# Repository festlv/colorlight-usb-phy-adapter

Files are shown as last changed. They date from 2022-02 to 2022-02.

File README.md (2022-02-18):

USB ULPI phy for Colorlight i5 SOM development board
------------------------------------------------------

Hardware design for dual-PMOD style USB ULPI phy breakout board. 

By default, the design assumes that 24MHz oscillator provides clock to phy, and 60MHz clock generated by PHY is routed to FPGA.
It is possible to supply 24MHz clock from FPGA- see schematic for details.

The design is most likely compatible with several SMSC/Microchip USB phy's from the same series, using different oscillator frequencies (for instance, this board
was first designed for USB3317C, but it went out of stock while the board was designed).

Change history
--------------------

__Revision 0__:

   * VDD1.8 was not connected, as I assumed USB3315C has internal 1.8V regulator. It does not.
   * After bodging a regulator, the design enumerates using LUNA gateware

__Revision 1__:

   * Added 1.8V LDO which was required for the used phy

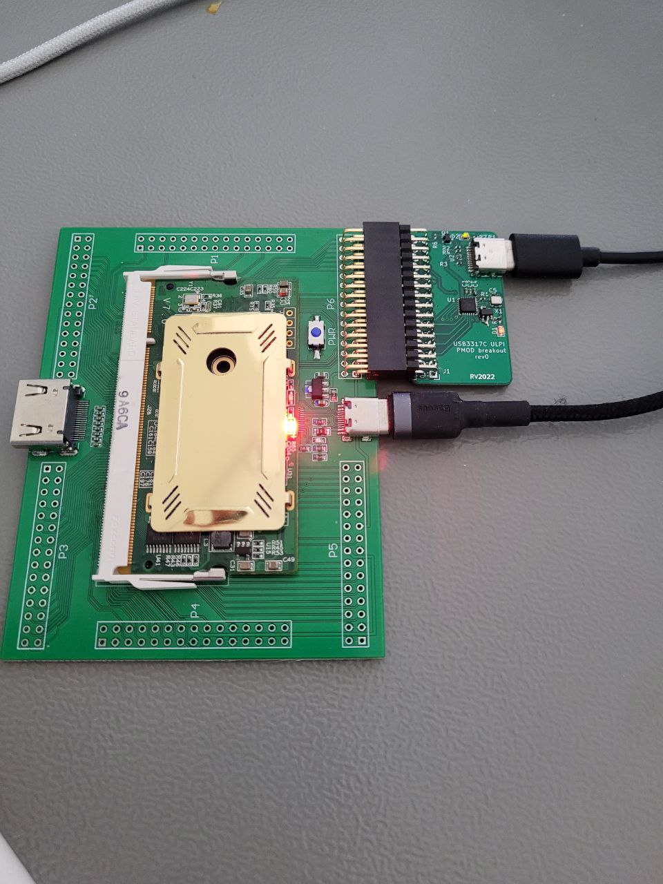
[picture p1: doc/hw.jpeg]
Image of hardware connected to colorlight i5 development board


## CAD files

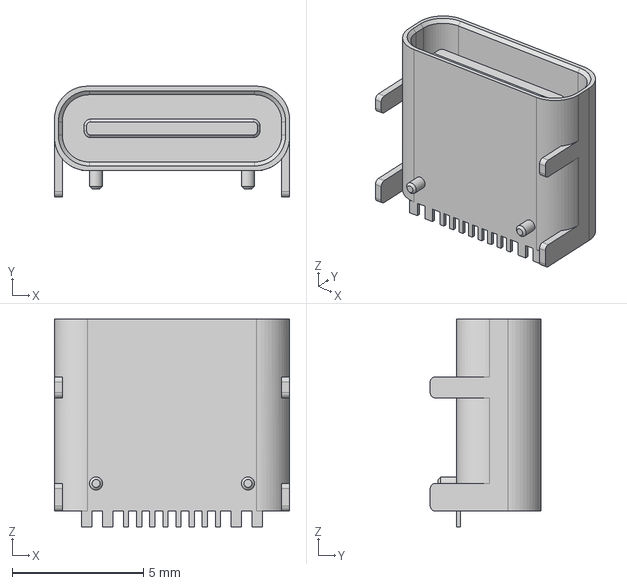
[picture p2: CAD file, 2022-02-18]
HRO TYPE-C-31-M-12.step
8.94 x 4.21 x 7.90 mm

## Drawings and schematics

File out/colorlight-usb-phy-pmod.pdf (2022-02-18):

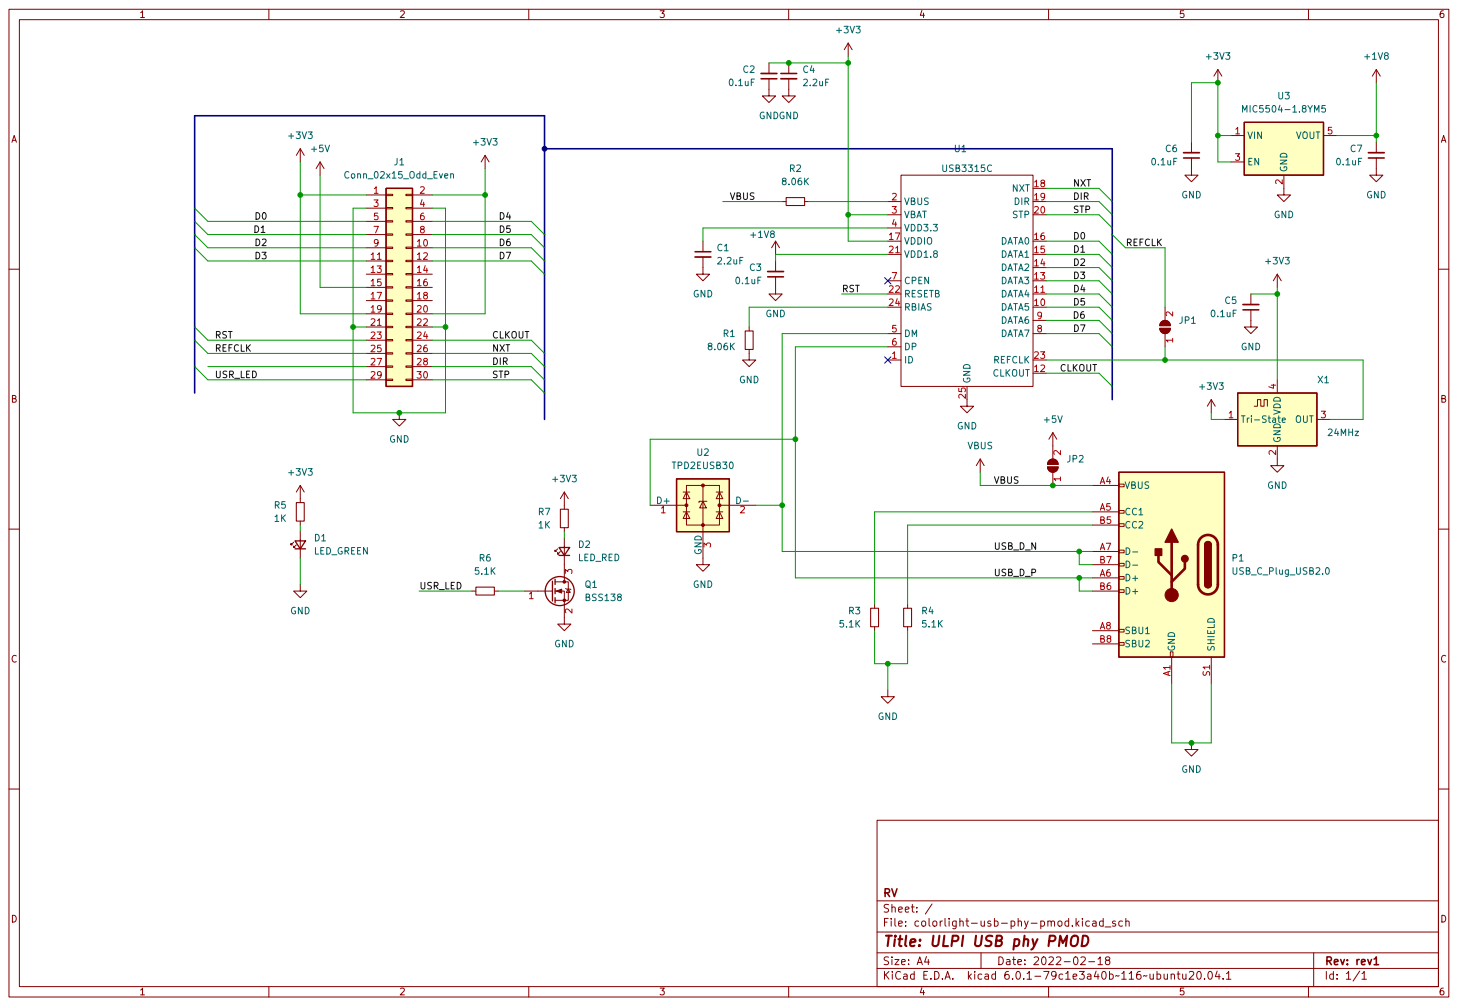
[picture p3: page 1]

File: colorlight-usb-phy-pmod.kicad_sch Sheet: / RV

Id: 1/1 Title: ULPI USB phy PMOD

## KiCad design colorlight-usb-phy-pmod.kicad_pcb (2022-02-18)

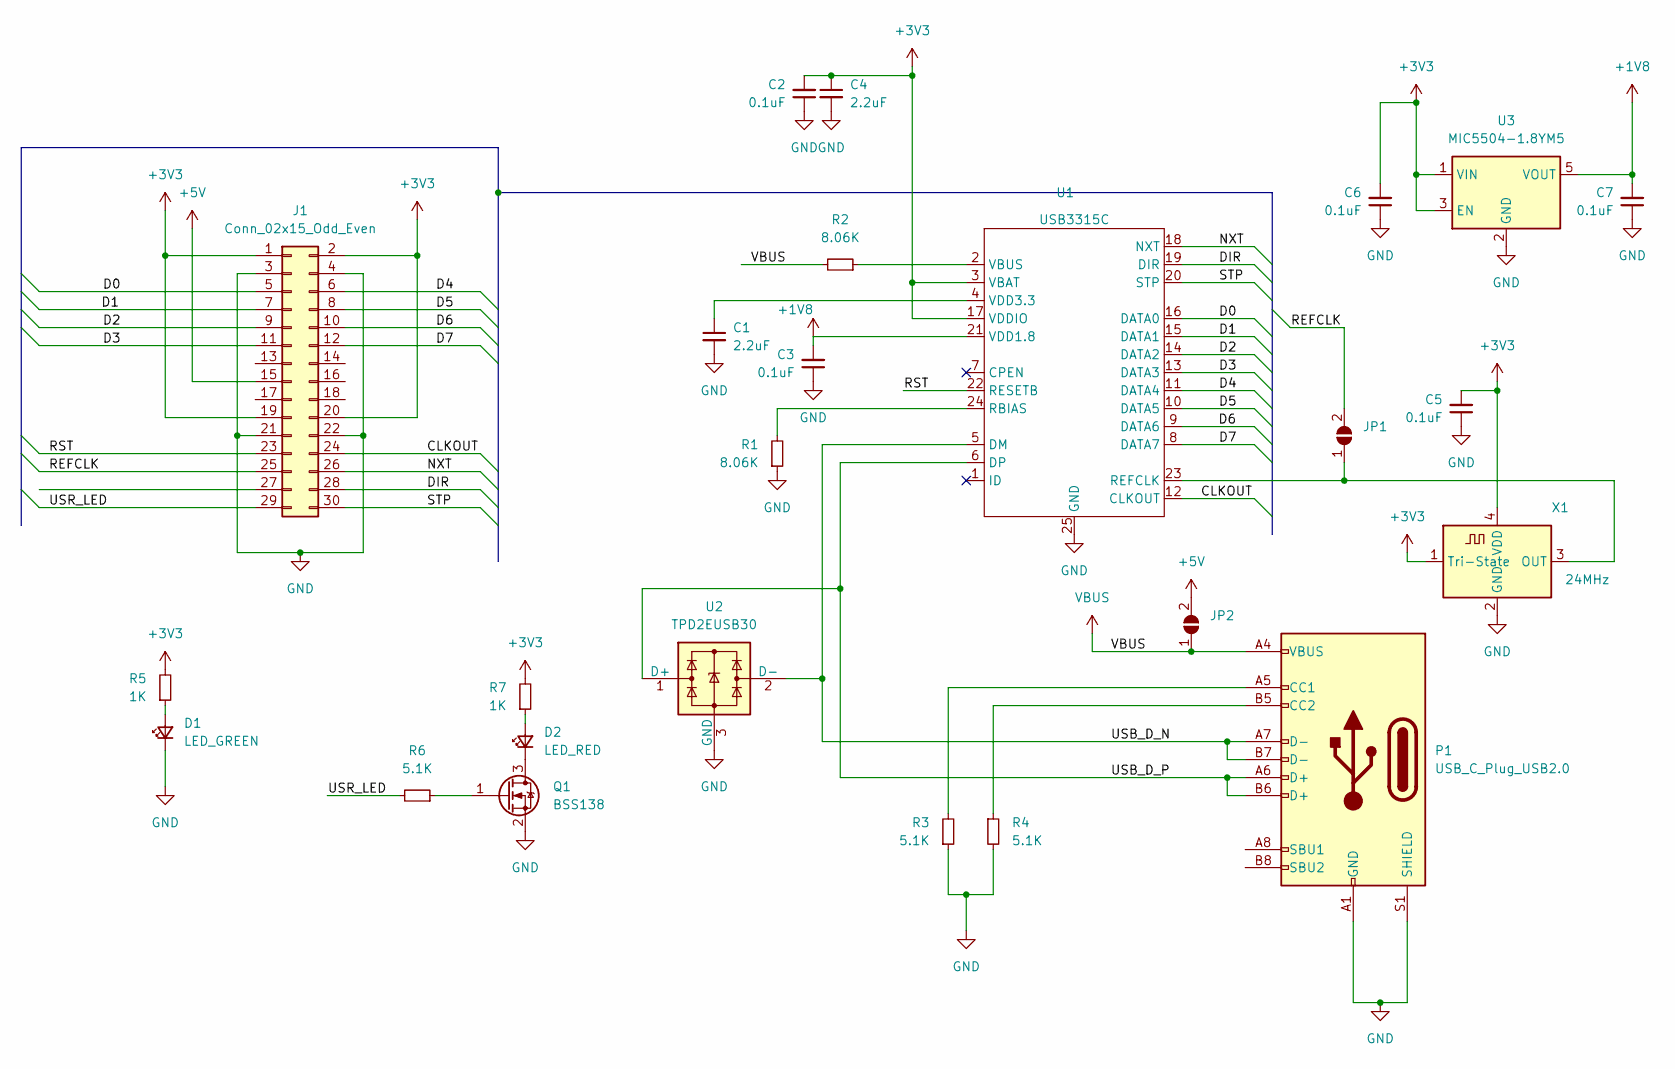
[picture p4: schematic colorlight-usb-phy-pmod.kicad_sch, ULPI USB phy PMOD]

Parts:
C1, C4: 2.2uF; C_0402_1005Metric
C2, C3, C5, C6, C7: 0.1uF; C_0402_1005Metric
D1: LED_GREEN; LED_0603_1608Metric
D2: LED_RED; LED_0603_1608Metric
J1: Conn_02x15_Odd_Even; PinHeader_2x15_P2.54mm_Horizontal
JP1, JP2: SolderJumper_2_Open; SolderJumper-2_P1.3mm_Open_TrianglePad1.0x1.5mm
P1: USB_C_Plug_USB2.0; USB_C_Receptacle_HRO_TYPE-C-31-M-12; MPN TYPE-C-31-M-12
Q1: BSS138; SOT-323_SC-70; MPN BSS138PW,115
R1, R2: 8.06K; R_0402_1005Metric
R3, R4, R6: 5.1K; R_0402_1005Metric
R5, R7: 1K; R_0402_1005Metric
U1: USB3315C; QFN-24-1EP_4x4mm_P0.5mm_EP2.6x2.6mm_ThermalVias; MPN USB3315C-CP-TR
U2: TPD2EUSB30; Texas_DRT-3
U3: MIC5504-1.8YM5; SOT-23-5
X1: 24MHz; Oscillator_SMD_ECS_2520MV-xxx-xx-4Pin_2.5x2.0mm; MPN ECS-2520MVLC-240-BN-TR

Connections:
+1V8: C3.2, C7.2, U1.21 (VDD1.8), U3.5 (VOUT)
+3V3: C2.2, C4.1, C5.2, C6.2, J1.1, J1.2, J1.19, J1.20, R5.2, R7.2, U1.3 (VBAT), U1.17 (VDDIO), U3.1 (VIN), U3.3 (EN), X1.1 (Tri-State), X1.4 (VDD)
+5V: J1.15, JP2.2 (B)
/CLKOUT: J1.24, U1.12 (CLKOUT)
/D0: J1.5, U1.16 (DATA0)
/D1: J1.7, U1.15 (DATA1)
/D2: J1.9, U1.14 (DATA2)
/D3: J1.11, U1.13 (DATA3)
/D4: J1.6, U1.11 (DATA4)
/D5: J1.8, U1.10 (DATA5)
/D6: J1.10, U1.9 (DATA6)
/D7: J1.12, U1.8 (DATA7)
/DIR: J1.28, U1.19 (DIR)
/NXT: J1.26, U1.18 (NXT)
/REFCLK: J1.25, JP1.2 (B)
/RST: J1.23, U1.22 (RESETB)
/STP: J1.30, U1.20 (STP)
/USB_D_N: P1.A7 (D-), P1.B7 (D-), U1.5 (DM), U2.2 (D-)
/USB_D_P: P1.A6 (D+), P1.B6 (D+), U1.6 (DP), U2.1 (D+)
/USR_LED: J1.29, R6.2
GND: C1.2, C2.1, C3.1, C4.2, C5.1, C6.1, C7.1, D1.1 (K), J1.3, J1.4, J1.21, J1.22, P1.A1 (GND), P1.A12 (GND), P1.B1 (GND), P1.B12 (GND), P1.S1 (SHIELD), Q1.2 (S), R1.1, R3.1, R4.2, U1.25 (GND), U2.3 (GND), U3.2 (GND), X1.2 (GND)
unnamed: C1.1, U1.4 (VDD3.3)
unnamed: D1.2 (A), R5.1
unnamed: D2.1 (K), Q1.3 (D)
unnamed: D2.2 (A), R7.1
unnamed: JP1.1 (A), U1.23 (REFCLK), X1.3 (OUT)
unnamed: P1.A5 (CC1), R3.2
unnamed: P1.B5 (CC2), R4.1
unnamed: Q1.1 (G), R6.1
unnamed: R1.2, U1.24 (RBIAS)
unnamed: R2.1, U1.2 (VBUS)
VBUS: JP2.1 (A), P1.A4 (VBUS), P1.A9 (VBUS), P1.B4 (VBUS), P1.B9 (VBUS), R2.2

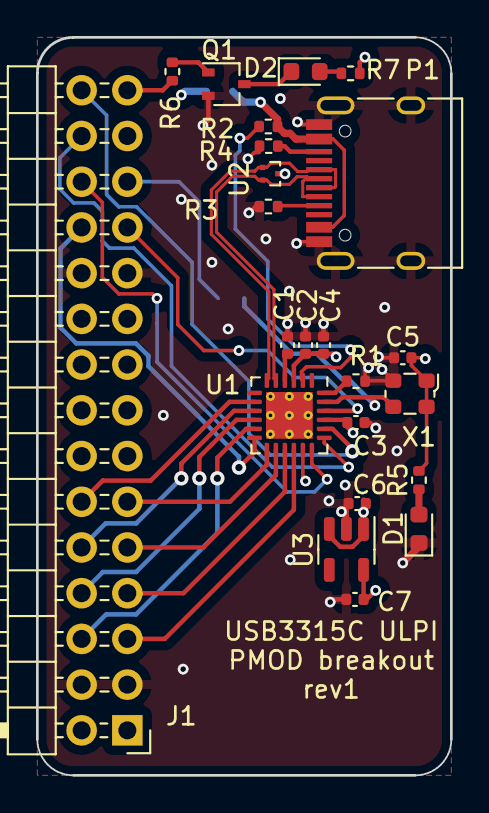
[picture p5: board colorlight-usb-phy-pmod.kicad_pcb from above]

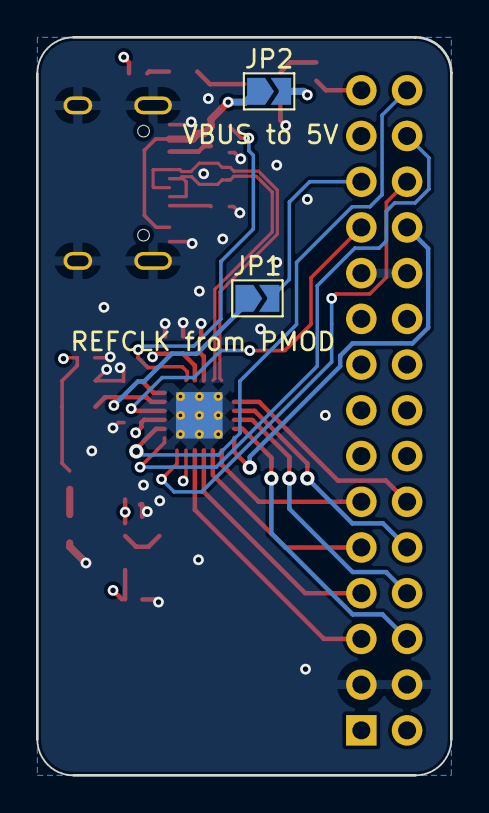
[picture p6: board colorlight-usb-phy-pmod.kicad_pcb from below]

Board: 4 copper layers, 23.0 x 41.0 mm, 25 parts (2 on the bottom side), 32 nets.
